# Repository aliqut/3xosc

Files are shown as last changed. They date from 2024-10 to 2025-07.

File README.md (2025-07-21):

# 3xOsc
3xOsc | 3 VCO Eurorack Module

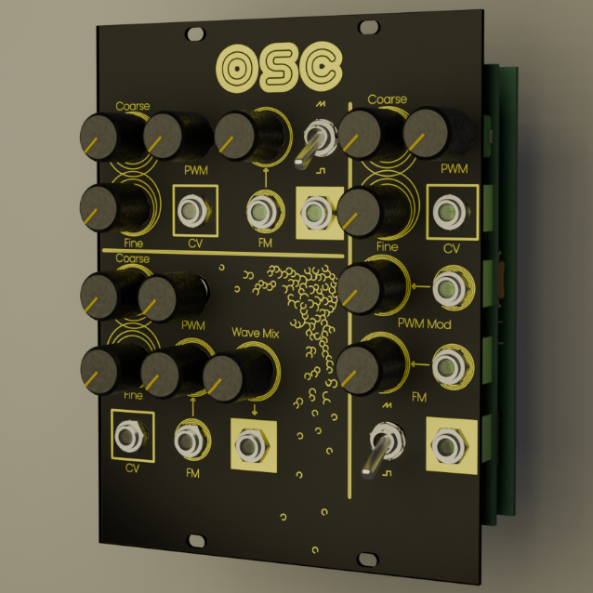
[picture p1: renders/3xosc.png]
render


This is a Eurorack format VCO synth module, based on Moritz Klein's VCO design.

The module was designed using KiCad.

---

**Features**:

Each of the 3 oscillators has:
  - Coarse and fine tuning knobs
  - a PWM (Pulse-width Modulation) knob
  - a FM (Frequency Modulation) knob and CV (Control Voltage) input

Controls unique to each oscillator:
- Oscillator 1:
  - Saw/Pulse switch
- Oscillator 2:
  - Saw/Pulse wave mix knob
- Oscillator 3:
  - Saw/Pulse switch
  - PWM modulation input, and modulation amount knob 

# Build Guide

1. Download the Gerber files from each board's '.gerbers' folder.
2. If you want to make any modifications to the schematics, download the schematics, make your modifications, and regenerate new Gerbers
3. View the components required from the `BOM.csv` file. (If you have made any changes to the schematics, it is best to regenerate the BOMs).
4. Order all the components needed
5. Send the Gerber files for PCB manufacturing, you can use [PCBShopper](https://pcbshopper.com/) to compare prices across various manufacturers.
6. Assemble the module

- **Notes**
  - Generic 1/4W 1% resistors will work for the build. 
  - The potentiometers are all linear.
    - For the coarse tuning knobs, you can use logarithmic pots if you prefer.
  - In addition to the components in the BOM, you will need M3 bolts to mount the module into your case, and hex nuts to mount the front panel onto the components (these usually come packaged with all the interface components).

Once you have your PCBs and components, refer to the BOM and schematic to solder the components onto the board.

The module is split into three boards, the main board, the connector board, and the front panel. You can make your own front panel if you'd prefer. 

The front panel board has no electrical connections and is purely aesthetic. I recommend letting your PCB manufacturer know this to avoid any issues.

The main and connector board are connected via the pin headers on the top and bottom of the PCBs, make sure you orient the pin headers properly before soldering. The front panel is secured onto the connector board using hex nuts.

### Front Panel

_To view the front panel on KiCad, you need to install the fonts in the `fonts/` folder from this repo, or replace them with your font of choice._

To get the shiny gold finish for the exposed copper used for text/graphics, make sure you get your PCB manufactured with an ENIG finish. Most PCB manufacturers offer this as an option.

I went for a black solder mask, but you get the option to choose from many different colours when ordering your PCB.

# Contributing

Pull requests are the best way to propose changes to the schematics.

1. Fork the repo and create your branch from `master`.
2. Make your changes to the design.
3. If your change directly affects the module's functionality, update the documentation.
4. Issue pull request

## Any contributions you make will be under the GPL Software License

In short, when you submit code changes, your submissions are understood to be under the same GPL license that covers the project.

## Report issues using Github's Issues tab.

I use GitHub issues to track public bugs. Report a bug by opening a new issue.

**Issue Reports** tend to have:

- A quick summary and/or background
- Steps to reproduce
  - Be specific
- What you expected would happen
- What actually happens
- Notes (possibly including why you think this might be happening, or stuff you tried that didn't work)

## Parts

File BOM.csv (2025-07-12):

MAIN BOARD
# | Reference | Qty | Value | Component/Footprint | Notes
1 | C1, C2, C7 | 3 | 2.2nF | Disc capacitor: D4.7mm_W2.5mm_P5.00mm | All components are through hole
2 | C3, C4, C5, C6, C8 | 5 | 1uF | Disc capacitor: D3.0mm_W1.6mm_P2.50mm
3 | C9, C10 | 2 | 10uF | Electrolitic capacitor :CP_Radial_D5.0mm_P2.00mm
4 | D1, D2, D3, D4, D5 | 5 | DO-15 | DO-15 P5.08mm Vertical AnodeUp
5 | J1, J3 | 2 | Conn 01x32 Socket | Connector_PinHeader_2.54mm:PinHeader 1x32 | Buy a pair of male and female headers. This is for connecting the main board to the connector board.
6 | J2 | 1 | Conn 02x05 Odd_Even | Connector_PinHeader_2.54mm:PinHeader 2x05 | Eurorack power header, keyed box 02x05 pin header
7 | Q1, Q3, Q5 | 3 | BC558 Transistor | THT TO-92_Inline
8 | Q2, Q4, Q6 | 3 | BC548 Transistor | THT TO-92_Inline
9 | R1, R4, R5, R7, R11, R13, R16, R20, R34, R37, R39, R41, R43, R46, R17, R21, R22, R25, R27, R28, R30, R32, R47 | 23 | 100K | Metalic film resistor 1/4W L9.0mm_D3.2mm_P12.70mm_Horizontal
10 | R2, R9, R35 | 3 | 1K5 | Metalic film resistor 1/4W L6.3mm_D2.5mm_P10.16mm_Horizontal
11 | R3, R10, R36 | 3 | 1K | Potentiometer Bourns 3006Y Horizontal
12 | R6, R8, R12, R14, R38, R40 | 6 | 1M | Metalic film resistor 1/4W
13 | R15, R19 | 2 | 200K | Metalic film resistor 1/4W
14 | R18, R23, R45 | 3 | 33K | Metalic film resistor 1/4W
15 | R24, R26, R29, R31, R33 | 5 | 20K | Metalic film resistor 1/4W
16 | R42, R48 | 2 | 68K | Metalic film resistor 1/4W
17 | R44 | 1 | 14K | Metalic film resistor 1/4W
18 | R49, R50 | 2 | 1K | Metalic film resistor 1/4W
19 | R51, R52 | 2 | 10R | Metalic film resistor 1/4W
20 | TH1, TH2, TH3, TH5, TH6, TH8, TH9, TH10, TH12, TH4, TH7, TH11 | 12 | 10K | Disk NTC Thermistor
21 | U1 | 1 | 40106 | 40106 Schmitt Trigger Inverter IC THT
22 | U2, U3, U4 | 3 | TL074 | TL074 Op-Amp IC THT
CONNECTOR BOARD
# | Reference | Qty | Value |  | Notes
1 | J1, J2 | 2 | Conn_01x32_Socket | 2.54mm 01x32
2 | J3, J4, J5, J6, J7, J8, J9, J10, J11, J12 | 10 | Audio Jacks | Thonk AudioJacks:Jack 3.5mm QingPu WQP-PJ366ST Vertical | Thonkiconn Jack Sockets or clones
3 | RV1, RV4, RV5, RV9, RV10, RV14 | 6 | 100K | Potentiometer Alpha RD901F-40-00D Vertical Linear | Tuning pots. You can replace the coarse tuning pots with logarithmic ones if you prefer
4 | RV2, RV3, RV6, RV7, RV11, RV12, RV13 | 7 | 1M | Potentiometer Alpha RD901F-40-00D Vertical Linear
5 | RV8 | 1 | 250K | Potentiometer Alpha RD901F-40-00D Vertical Linear | PWM Pot
6 | SW1, SW2 | 2 | SPDT Switch | SPDT-ON-ON | SPDT. These have three legs.
7 | U1, U2, U3, U4 | 4 | DIP Socket IC 7x2 | DIP Sockets for IC 7x2 | Heavily recommended. Makes it easy to swap out ICs if you're troubleshooting, and protects the ICs from heat during soldering.

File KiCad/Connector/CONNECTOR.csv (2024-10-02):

# | Reference | Qty | Value | Footprint | DNP
1 | J1, J2 | 2 | Conn_01x32_Socket | Connector_PinHeader_2.54mm:PinHeader_1x32_P2.54mm_Vertical
2 | J3, J4, J5, J6, J7, J8, J9, J10, J11, J12 | 10 | AudioJack3 | Thonk_AudioJacks:Jack_3.5mm_QingPu_WQP-PJ366ST_Vertical
3 | RV1, RV4, RV5, RV9, RV10, RV14 | 6 | 100k | Potentiometer_THT:Potentiometer_Alpha_RD901F-40-00D_Single_Vertical
4 | RV2, RV3, RV6, RV7, RV11, RV12, RV13 | 7 | 1M | Potentiometer_THT:Potentiometer_Alpha_RD901F-40-00D_Single_Vertical
5 | RV8 | 1 | 250k | Potentiometer_THT:Potentiometer_Alpha_RD901F-40-00D_Single_Vertical
6 | SW1, SW2 | 2 | SW_SPDT | Thonk_AudioJacks:DWB1-SPDT-ON-ON

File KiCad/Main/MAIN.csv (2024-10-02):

# | Reference | Qty | Value | Footprint | DNP
1 | C1, C2, C7 | 3 | 2.2nF | Capacitor_THT:C_Disc_D4.7mm_W2.5mm_P5.00mm
2 | C3, C4, C5, C6, C8 | 5 | 1uF | Capacitor_THT:C_Disc_D3.0mm_W1.6mm_P2.50mm
3 | C9, C10 | 2 | 10uF | Capacitor_THT:CP_Radial_D5.0mm_P2.00mm
4 | D1, D2, D3, D4, D5 | 5 | D | Diode_THT:D_DO-15_P5.08mm_Vertical_AnodeUp
5 | J1, J3 | 2 | Conn_01x32_Socket | Connector_PinHeader_2.54mm:PinHeader_1x32_P2.54mm_Vertical
6 | J2 | 1 | Conn_02x05_Odd_Even | Connector_PinHeader_2.54mm:PinHeader_2x05_P2.54mm_Vertical
7 | Q1, Q3, Q5 | 3 | BC558 | Package_TO_SOT_THT:TO-92_Inline
8 | Q2, Q4, Q6 | 3 | BC548 | Package_TO_SOT_THT:TO-92_Inline
9 | R1, R4, R5, R7, R11, R13, R16, R20, R34, R37, R39, R41, R43, R46 | 14 | 100K | Resistor_THT:R_Axial_DIN0309_L9.0mm_D3.2mm_P12.70mm_Horizontal
10 | R2, R9, R35 | 3 | 1K5 | Resistor_THT:R_Axial_DIN0207_L6.3mm_D2.5mm_P10.16mm_Horizontal
11 | R3, R10, R36 | 3 | 1K | Potentiometer_THT:Potentiometer_Bourns_3006Y_Horizontal
12 | R6, R8, R12, R14, R38, R40 | 6 | 1M | Resistor_THT:R_Axial_DIN0207_L6.3mm_D2.5mm_P7.62mm_Horizontal
13 | R15, R19 | 2 | 200k | Resistor_THT:R_Axial_DIN0207_L6.3mm_D2.5mm_P10.16mm_Horizontal
14 | R17, R21, R22, R25, R27, R28, R30, R32, R47 | 9 | 100k | Resistor_THT:R_Axial_DIN0309_L9.0mm_D3.2mm_P12.70mm_Horizontal
15 | R18, R23, R45 | 3 | 33k | Resistor_THT:R_Axial_DIN0207_L6.3mm_D2.5mm_P10.16mm_Horizontal
16 | R24, R26, R29, R31 | 4 | 20k | Resistor_THT:R_Axial_DIN0207_L6.3mm_D2.5mm_P7.62mm_Horizontal
17 | R33 | 1 | 20K | Resistor_THT:R_Axial_DIN0207_L6.3mm_D2.5mm_P7.62mm_Horizontal
18 | R42, R48 | 2 | 68K | Resistor_THT:R_Axial_DIN0207_L6.3mm_D2.5mm_P10.16mm_Horizontal
19 | R44 | 1 | 14K | Resistor_THT:R_Axial_DIN0207_L6.3mm_D2.5mm_P10.16mm_Horizontal
20 | R49, R50 | 2 | 1K | Resistor_THT:R_Axial_DIN0207_L6.3mm_D2.5mm_P10.16mm_Horizontal
21 | R51, R52 | 2 | 10R | Resistor_THT:R_Axial_DIN0207_L6.3mm_D2.5mm_P10.16mm_Horizontal
22 | TH1, TH2, TH3, TH5, TH6, TH8, TH9, TH10, TH12 | 9 | 10K | Resistor_THT:R_Axial_DIN0204_L3.6mm_D1.6mm_P2.54mm_Vertical
23 | TH4, TH7, TH11 | 3 | 10k | Resistor_THT:R_Axial_DIN0204_L3.6mm_D1.6mm_P2.54mm_Vertical
24 | U1 | 1 | 40106 | Package_DIP:DIP-14_W7.62mm_Socket
25 | U2, U3, U4 | 3 | TL074 | Package_DIP:DIP-14_W7.62mm_Socket

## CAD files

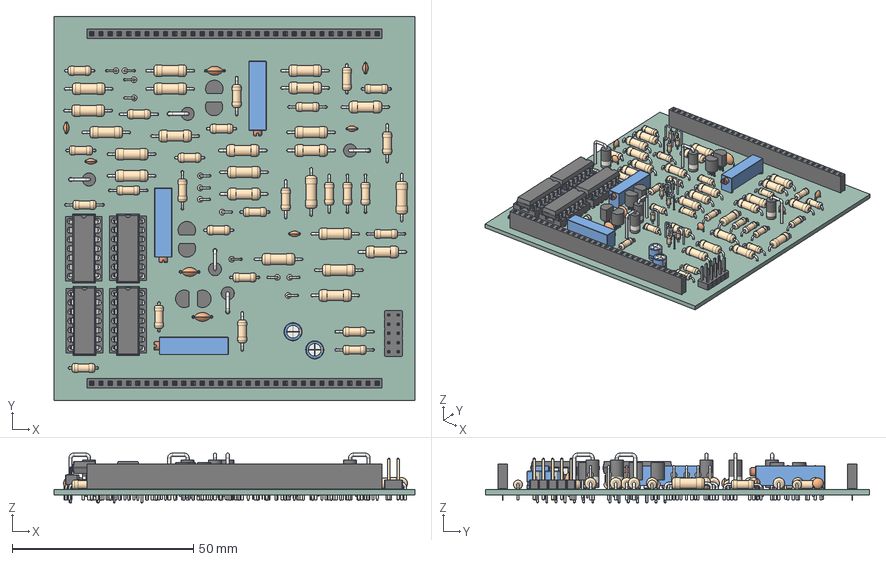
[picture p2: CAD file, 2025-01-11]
KiCad/Main/MAIN.step
99.6 x 106.0 x 13.7 mm
3X VCO PCB

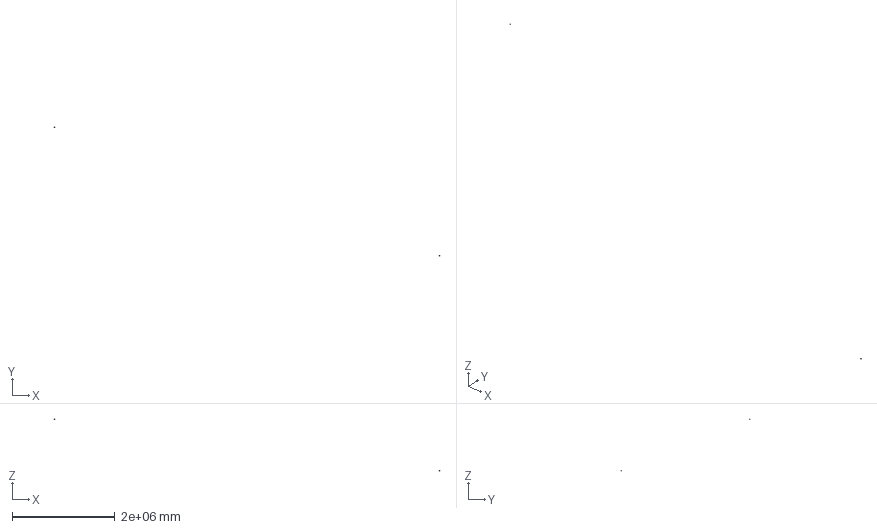
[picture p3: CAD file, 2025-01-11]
KiCad/Connector/CONNECTOR.step
7500096.3 x 2500076.7 x 1000028.5 mm
VCO PANEL PCB

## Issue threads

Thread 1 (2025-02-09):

About the Box power header orientation

IhnnChocoFarms, 2025-02-09:
Hi, while not exactly an issue there is no info on the orientation of the 2x5 box pin header. I would assume that below the square pad would be the stripe so the square pad indicates the pin 1, -12v.
Is this correct ?
Thanks

aliqut, 2025-02-09:
Your assumption is correct. The square pad (pin 1) is -12V.

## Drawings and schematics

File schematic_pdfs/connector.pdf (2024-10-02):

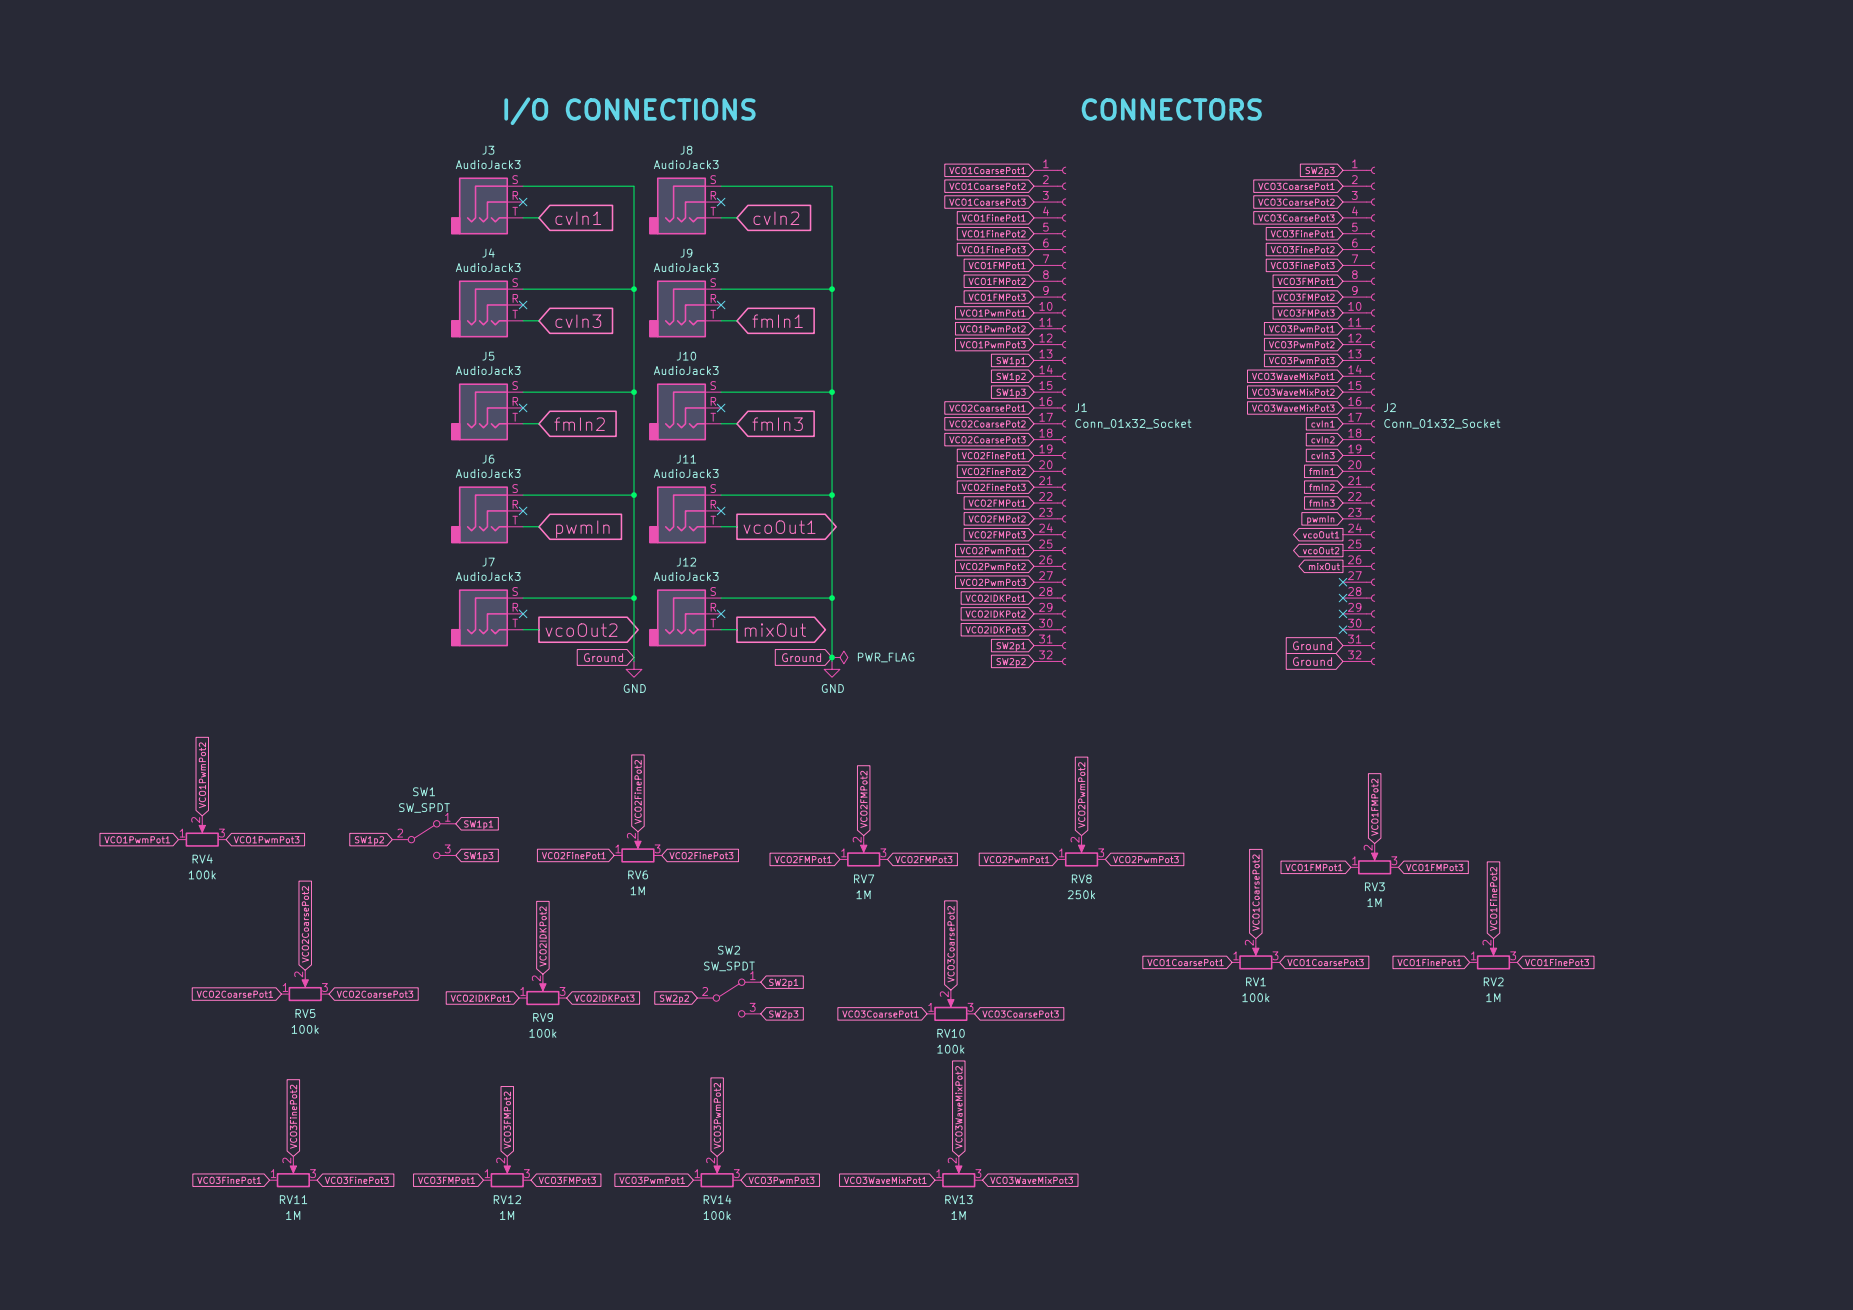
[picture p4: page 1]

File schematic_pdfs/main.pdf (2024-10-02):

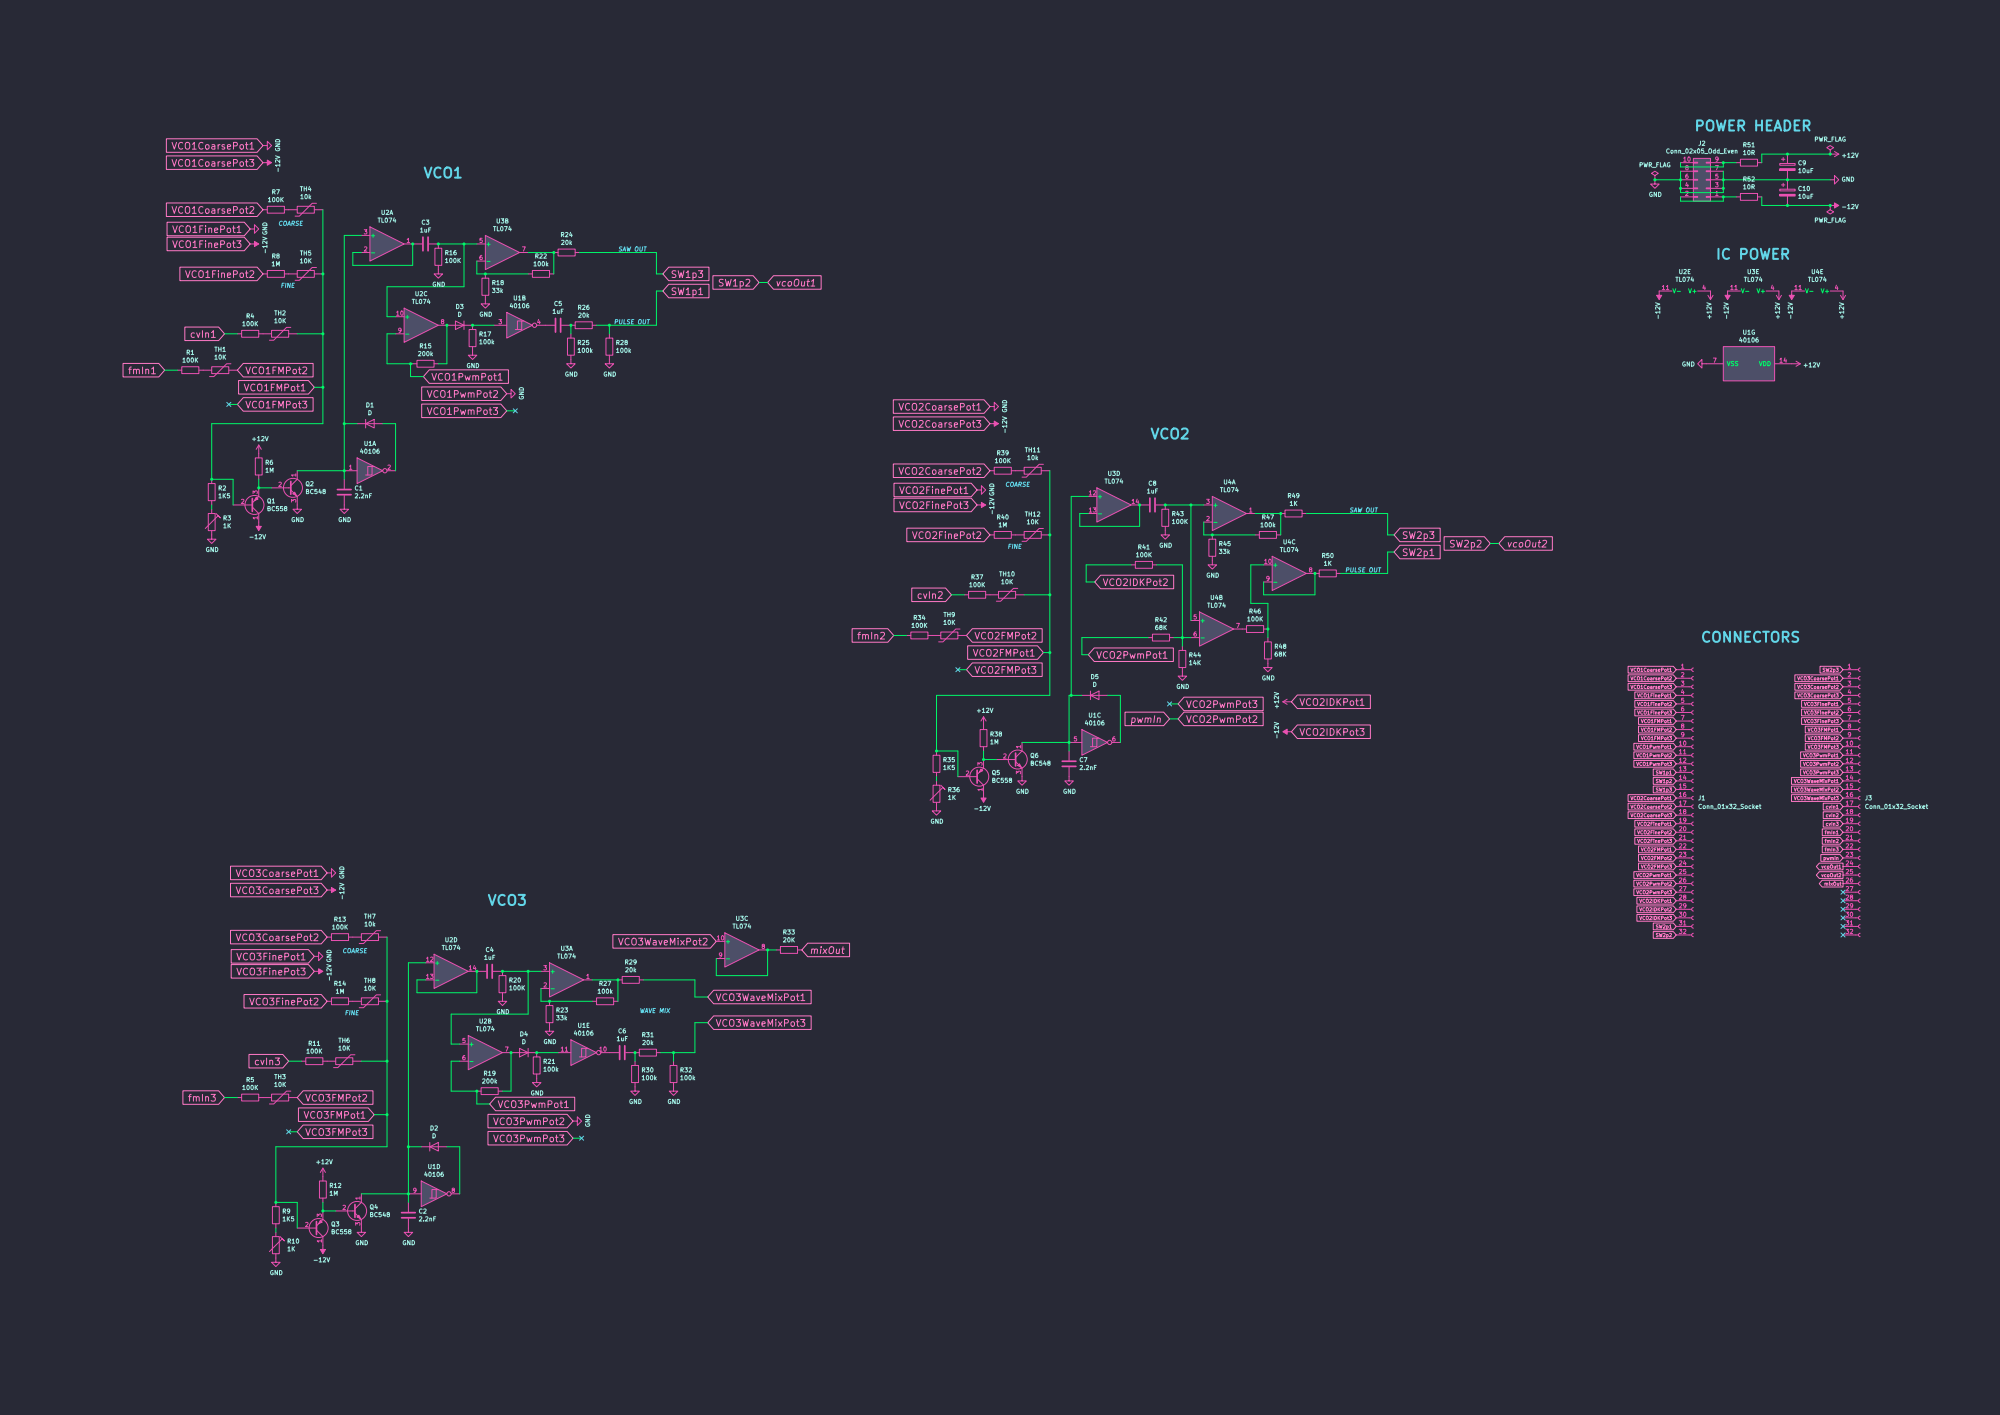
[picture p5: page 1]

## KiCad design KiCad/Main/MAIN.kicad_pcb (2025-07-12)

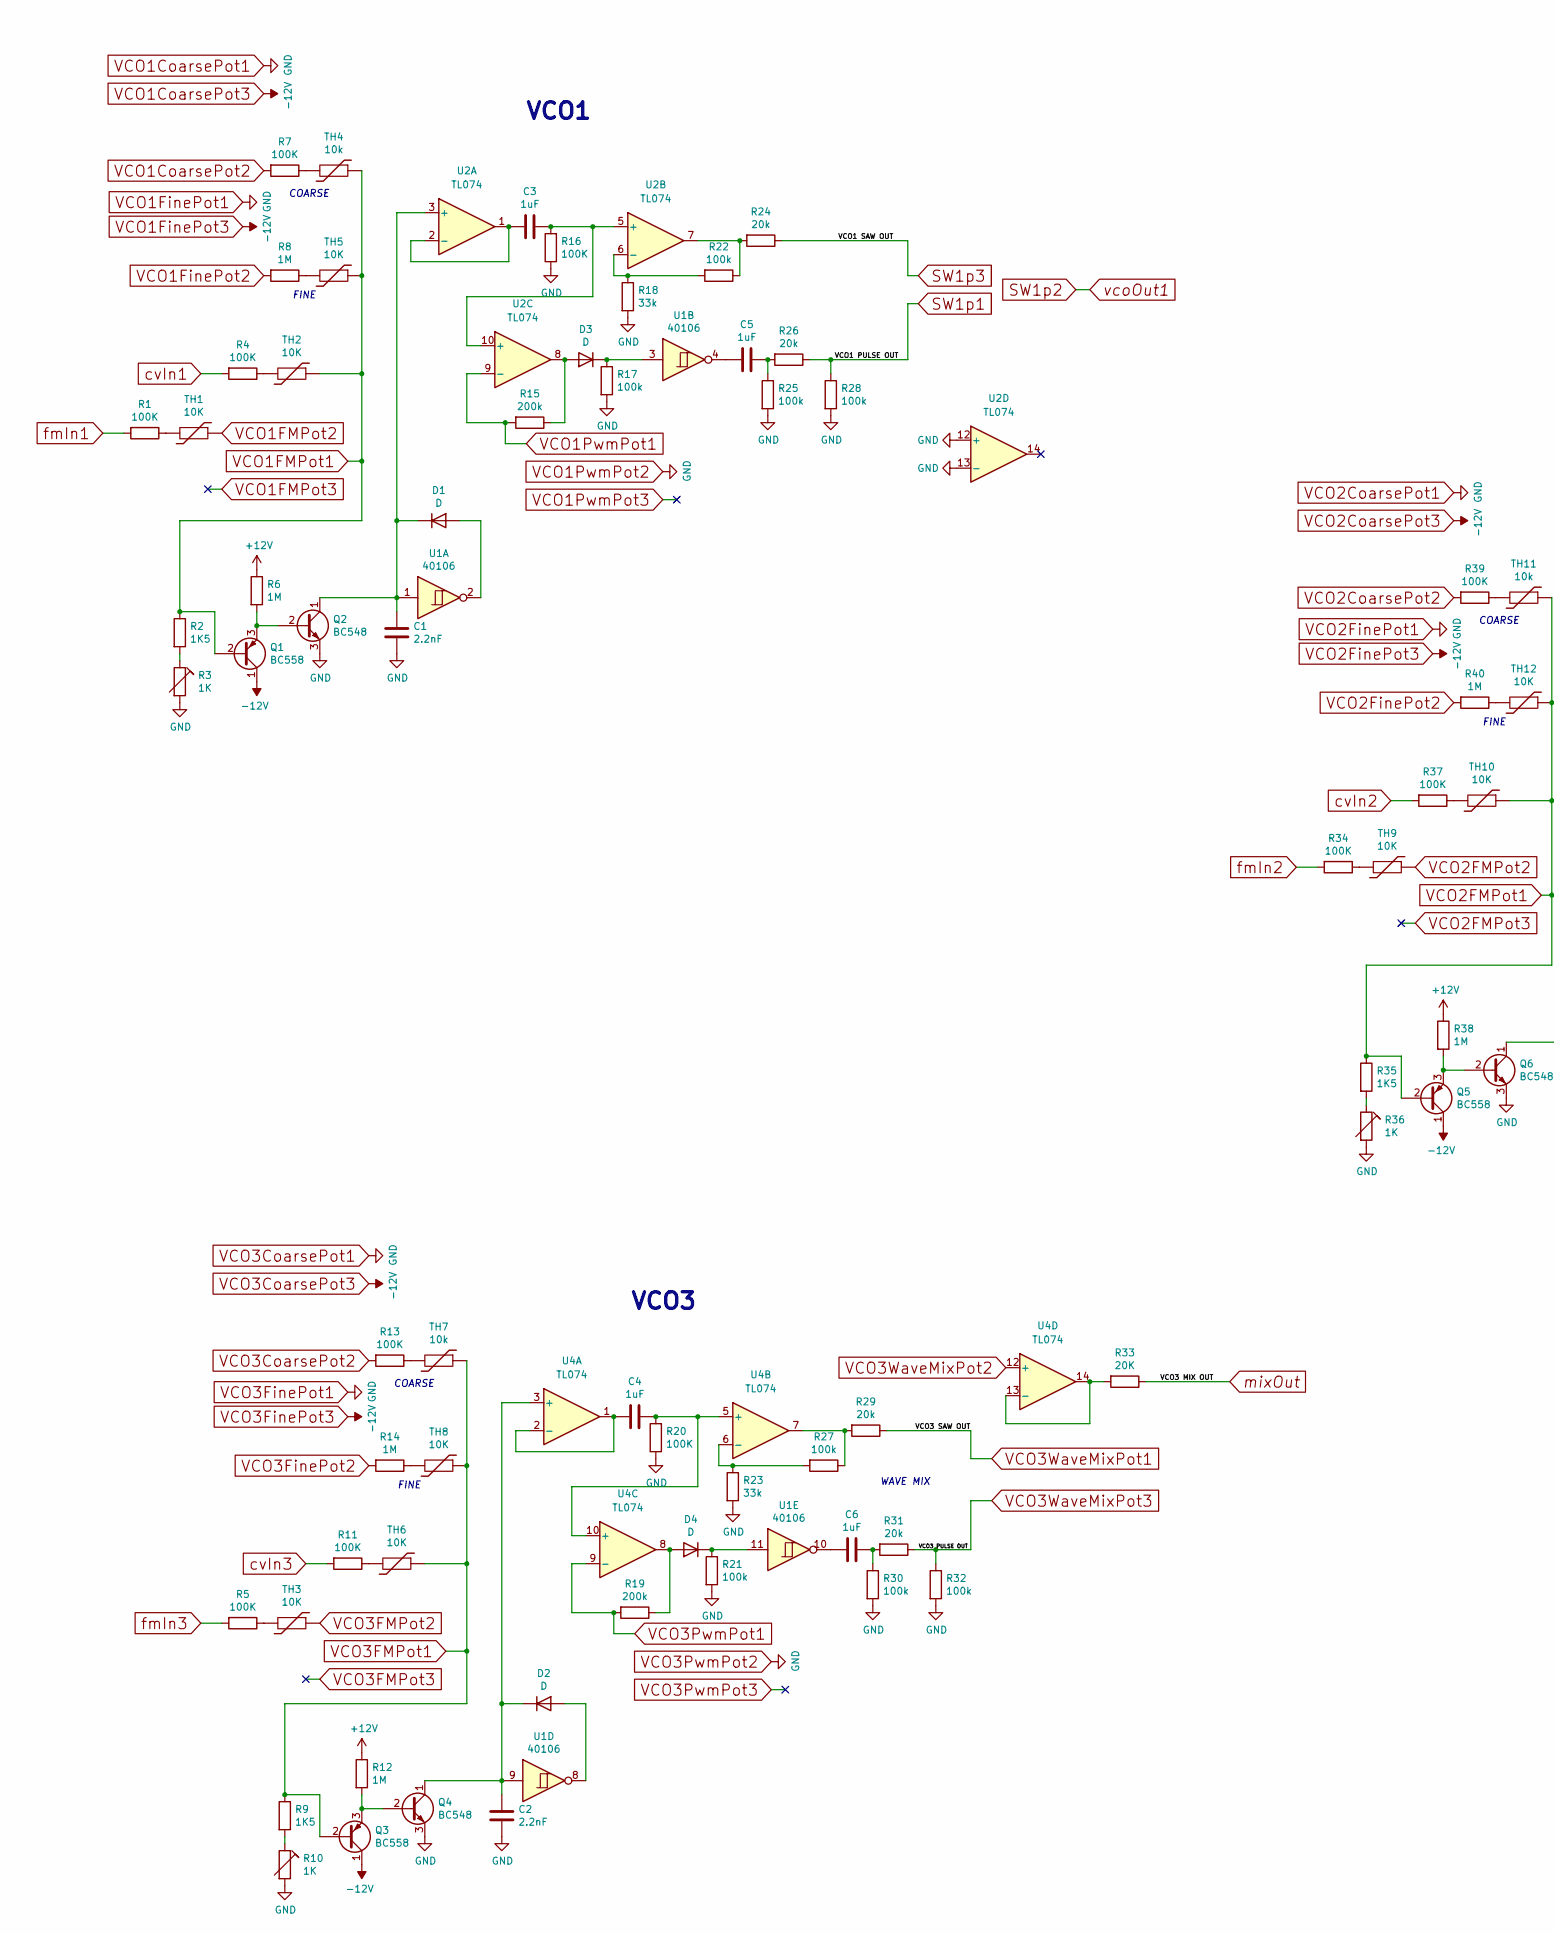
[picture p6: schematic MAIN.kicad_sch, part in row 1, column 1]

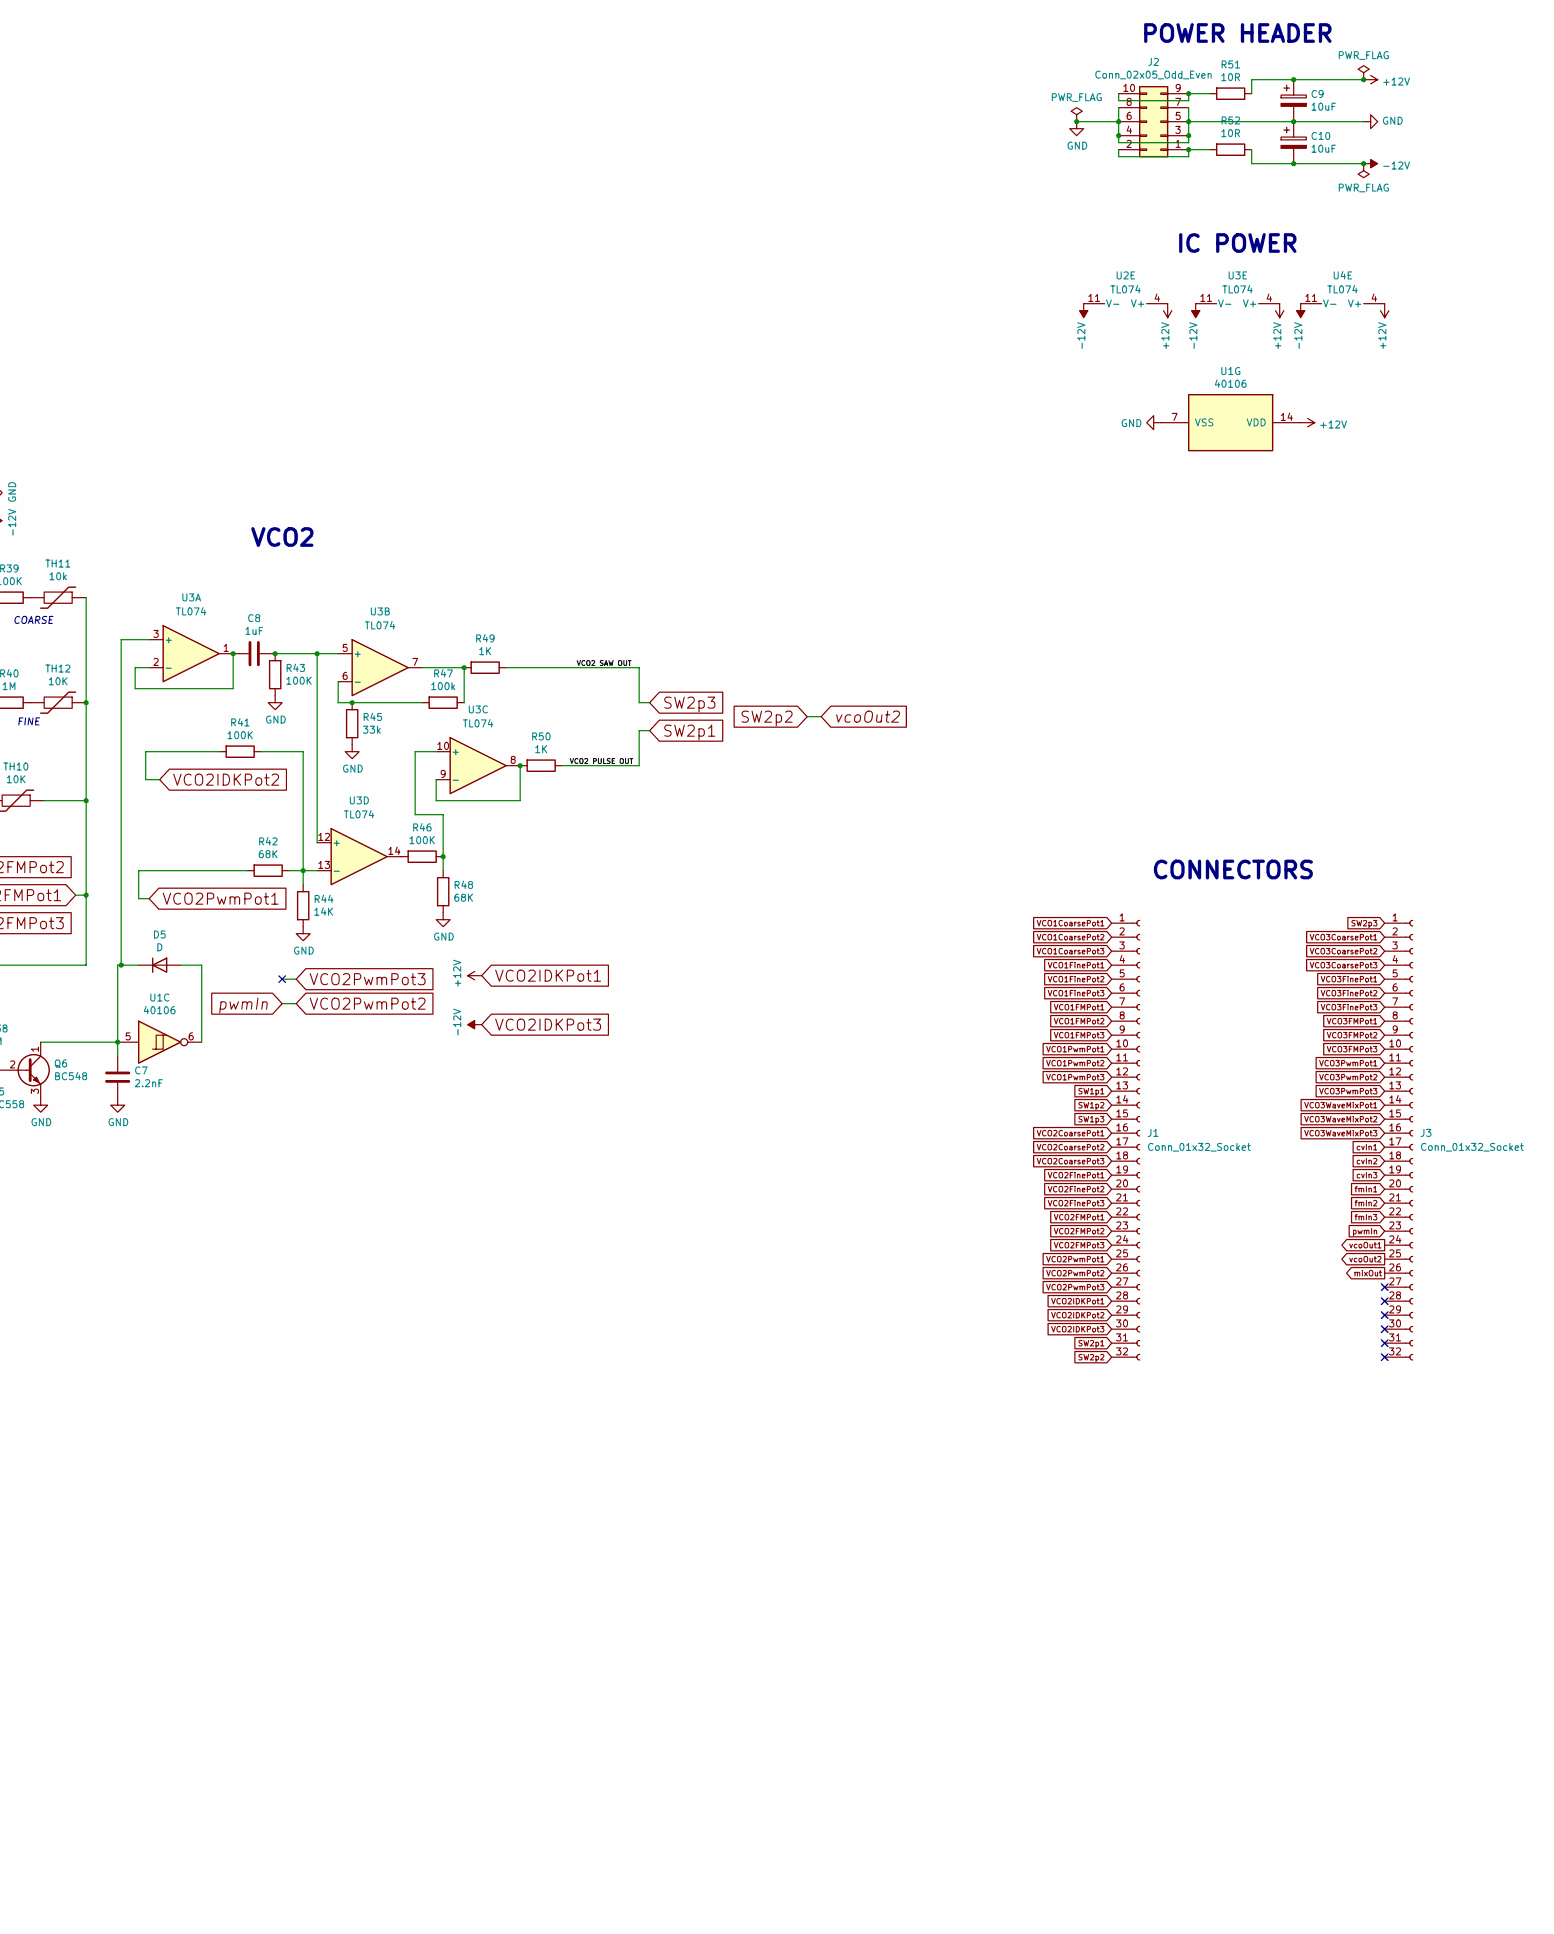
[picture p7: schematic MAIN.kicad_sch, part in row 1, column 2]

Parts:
C1, C2, C7: 2.2nF; C_Disc_D4.7mm_W2.5mm_P5.00mm
C3, C4, C5, C6, C8: 1uF; C_Disc_D3.0mm_W1.6mm_P2.50mm
C9, C10: 10uF; CP_Radial_D5.0mm_P2.00mm
D1, D2, D3, D4, D5: D; D_DO-15_P5.08mm_Vertical_AnodeUp
J1, J3: Conn_01x32_Socket; PinHeader_1x32_P2.54mm_Vertical
J2: Conn_02x05_Odd_Even; PinHeader_2x05_P2.54mm_Vertical
Q1, Q3, Q5: BC558; TO-92_Inline
Q2, Q4, Q6: BC548; TO-92_Inline
R1, R4, R5, R7, R11, R13, R16, R20, R34, R37, R39, R41, R43, R46: 100K; R_Axial_DIN0309_L9.0mm_D3.2mm_P12.70mm_Horizontal
R2, R9, R35: 1K5; R_Axial_DIN0207_L6.3mm_D2.5mm_P10.16mm_Horizontal
R3, R10, R36: 1K; Potentiometer_Bourns_3006Y_Horizontal
R6, R8, R12, R14, R38, R40: 1M; R_Axial_DIN0207_L6.3mm_D2.5mm_P7.62mm_Horizontal
R15, R19: 200k; R_Axial_DIN0207_L6.3mm_D2.5mm_P10.16mm_Horizontal
R17, R21, R22, R25, R27, R28, R30, R32, R47: 100k; R_Axial_DIN0309_L9.0mm_D3.2mm_P12.70mm_Horizontal
R18, R23, R45: 33k; R_Axial_DIN0207_L6.3mm_D2.5mm_P10.16mm_Horizontal
R24, R26, R29, R31: 20k; R_Axial_DIN0207_L6.3mm_D2.5mm_P7.62mm_Horizontal
R33: 20K; R_Axial_DIN0207_L6.3mm_D2.5mm_P7.62mm_Horizontal
R42, R48: 68K; R_Axial_DIN0207_L6.3mm_D2.5mm_P10.16mm_Horizontal
R44: 14K; R_Axial_DIN0207_L6.3mm_D2.5mm_P10.16mm_Horizontal
R49, R50: 1K; R_Axial_DIN0207_L6.3mm_D2.5mm_P10.16mm_Horizontal
R51, R52: 10R; R_Axial_DIN0207_L6.3mm_D2.5mm_P10.16mm_Horizontal
TH1, TH2, TH3, TH5, TH6, TH8, TH9, TH10, TH12: 10K; R_Axial_DIN0204_L3.6mm_D1.6mm_P2.54mm_Vertical
TH4, TH7, TH11: 10k; R_Axial_DIN0204_L3.6mm_D1.6mm_P2.54mm_Vertical
U1: 40106; DIP-14_W7.62mm_Socket
U2, U3, U4: TL074; DIP-14_W7.62mm_Socket

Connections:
unnamed: C5.1, R25.1, R26.2
unnamed: C5.2, U1.4
unnamed: C6.1, R30.1, R31.2
unnamed: C6.2, U1.10
unnamed: D1.2 (A), U1.2
unnamed: C1.1, D1.1 (K), Q2.1 (C), U1.1, U2.3 (+)
unnamed: D2.2 (A), U1.8
unnamed: C2.1, D2.1 (K), Q4.1 (C), U1.9, U4.3 (+)
unnamed: D3.2 (A), R15.1, U2.8
unnamed: D3.1 (K), R17.1, U1.3
unnamed: D4.2 (A), R19.1, U4.8
unnamed: D4.1 (K), R21.1, U1.11
unnamed: D5.2 (A), U1.6
unnamed: C7.1, D5.1 (K), Q6.1 (C), U1.5, U3.3 (+)
unnamed: J2.1, J2.2, R52.2
unnamed: J2.9, J2.10, R51.2
unnamed: Q1.3 (E), Q2.2 (B), R6.2
unnamed: Q3.3 (E), Q4.2 (B), R12.2
unnamed: Q5.3 (E), Q6.2 (B), R38.2
unnamed: R1.1, TH1.2
unnamed: R2.2, R3.1
unnamed: R4.1, TH2.2
unnamed: R5.1, TH3.2
unnamed: R7.1, TH4.2
unnamed: R8.1, TH5.2
unnamed: R9.2, R10.1
unnamed: R11.1, TH6.2
unnamed: R13.1, TH7.2
unnamed: R14.1, TH8.2
unnamed: R22.1, R24.2, U2.7
unnamed: R27.1, R29.2, U4.7
unnamed: R34.1, TH9.2
unnamed: R35.2, R36.1
unnamed: R37.1, TH10.2
unnamed: R39.1, TH11.2
unnamed: R40.1, TH12.2
unnamed: R46.2, U3.14
unnamed: R47.1, R49.2, U3.7
unnamed: C3.2, U2.1, U2.2 (-)
unnamed: C3.1, R16.2, U2.5 (+), U2.10 (+)
unnamed: R18.1, R22.2, U2.6 (-)
unnamed: C8.2, U3.1, U3.2 (-)
unnamed: C8.1, R43.2, U3.5 (+), U3.12 (+)
unnamed: R45.1, R47.2, U3.6 (-)
unnamed: R46.1, R48.1, U3.10 (+)
unnamed: R50.2, U3.8, U3.9 (-)
unnamed: R41.1, R42.1, R44.1, U3.13 (-)
unnamed: C4.2, U4.1, U4.2 (-)
unnamed: C4.1, R20.2, U4.5 (+), U4.10 (+)
unnamed: R23.1, R27.2, U4.6 (-)
unnamed: R33.2, U4.13 (-), U4.14
SW1p1: J1.13, R26.1, R28.1
SW1p2: J1.14, J3.24
SW1p3: J1.15, R24.1
SW2p1: J1.31, R50.1
SW2p2: J1.32, J3.25
SW2p3: J3.1, R49.1
VCO1CoarsePot1: C1.2, C2.2, C7.2, C9.2, C10.1, J1.1, J1.4, J1.11, J1.16, J1.19, J2.3, J2.4, J2.5, J2.6, J2.7, J2.8, J3.2, J3.5, J3.12, Q2.3 (E), Q4.3 (E), Q6.3 (E), R3.2, R10.2, R16.1, R17.2, R18.2, R20.1, R21.2, R23.2, R25.2, R28.2, R30.2, R32.2, R36.2, R43.1, R44.2, R45.2, R48.2, U1.7 (VSS), U2.12 (+), U2.13 (-)
VCO1CoarsePot2: J1.2, R7.2
VCO1CoarsePot3: C10.2, J1.3, J1.6, J1.18, J1.21, J1.30, J3.4, J3.7, Q1.1 (C), Q3.1 (C), Q5.1 (C), R52.1, U2.11 (V-), U3.11 (V-), U4.11 (V-)
VCO1FMPot1: J1.7, Q1.2 (B), R2.1, TH2.1, TH4.1, TH5.1
VCO1FMPot2: J1.8, TH1.1
VCO1FMPot3: J1.9
VCO1FinePot2: J1.5, R8.2
VCO1PwmPot1: J1.10, R15.2, U2.9 (-)
VCO1PwmPot3: J1.12
VCO2CoarsePot2: J1.17, R39.2
VCO2FMPot1: J1.22, Q5.2 (B), R35.1, TH10.1, TH11.1, TH12.1
VCO2FMPot2: J1.23, TH9.1
VCO2FMPot3: J1.24
VCO2FinePot2: J1.20, R40.2
VCO2IDKPot1: C9.1, J1.28, R6.1, R12.1, R38.1, R51.1, U1.14 (VDD), U2.4 (V+), U3.4 (V+), U4.4 (V+)
VCO2IDKPot2: J1.29, R41.2
VCO2PwmPot1: J1.25, R42.2
VCO2PwmPot2: J1.26, J3.23
VCO2PwmPot3: J1.27
VCO3CoarsePot2: J3.3, R13.2
VCO3FMPot1: J3.8, Q3.2 (B), R9.1, TH6.1, TH7.1, TH8.1
VCO3FMPot2: J3.9, TH3.1
VCO3FMPot3: J3.10
VCO3FinePot2: J3.6, R14.2
VCO3PwmPot1: J3.11, R19.2, U4.9 (-)
VCO3PwmPot3: J3.13
VCO3WaveMixPot1: J3.14, R29.1
VCO3WaveMixPot2: J3.15, U4.12 (+)
VCO3WaveMixPot3: J3.16, R31.1, R32.1
cvIn1: J3.17, R4.2
cvIn2: J3.18, R37.2
cvIn3: J3.19, R11.2
fmIn1: J3.20, R1.2
fmIn2: J3.21, R34.2
fmIn3: J3.22, R5.2
mixOut: J3.26, R33.1

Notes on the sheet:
WAVE MIX
COARSE
VCO1
FINE
VCO3
IC POWER
POWER HEADER
CONNECTORS
VCO2

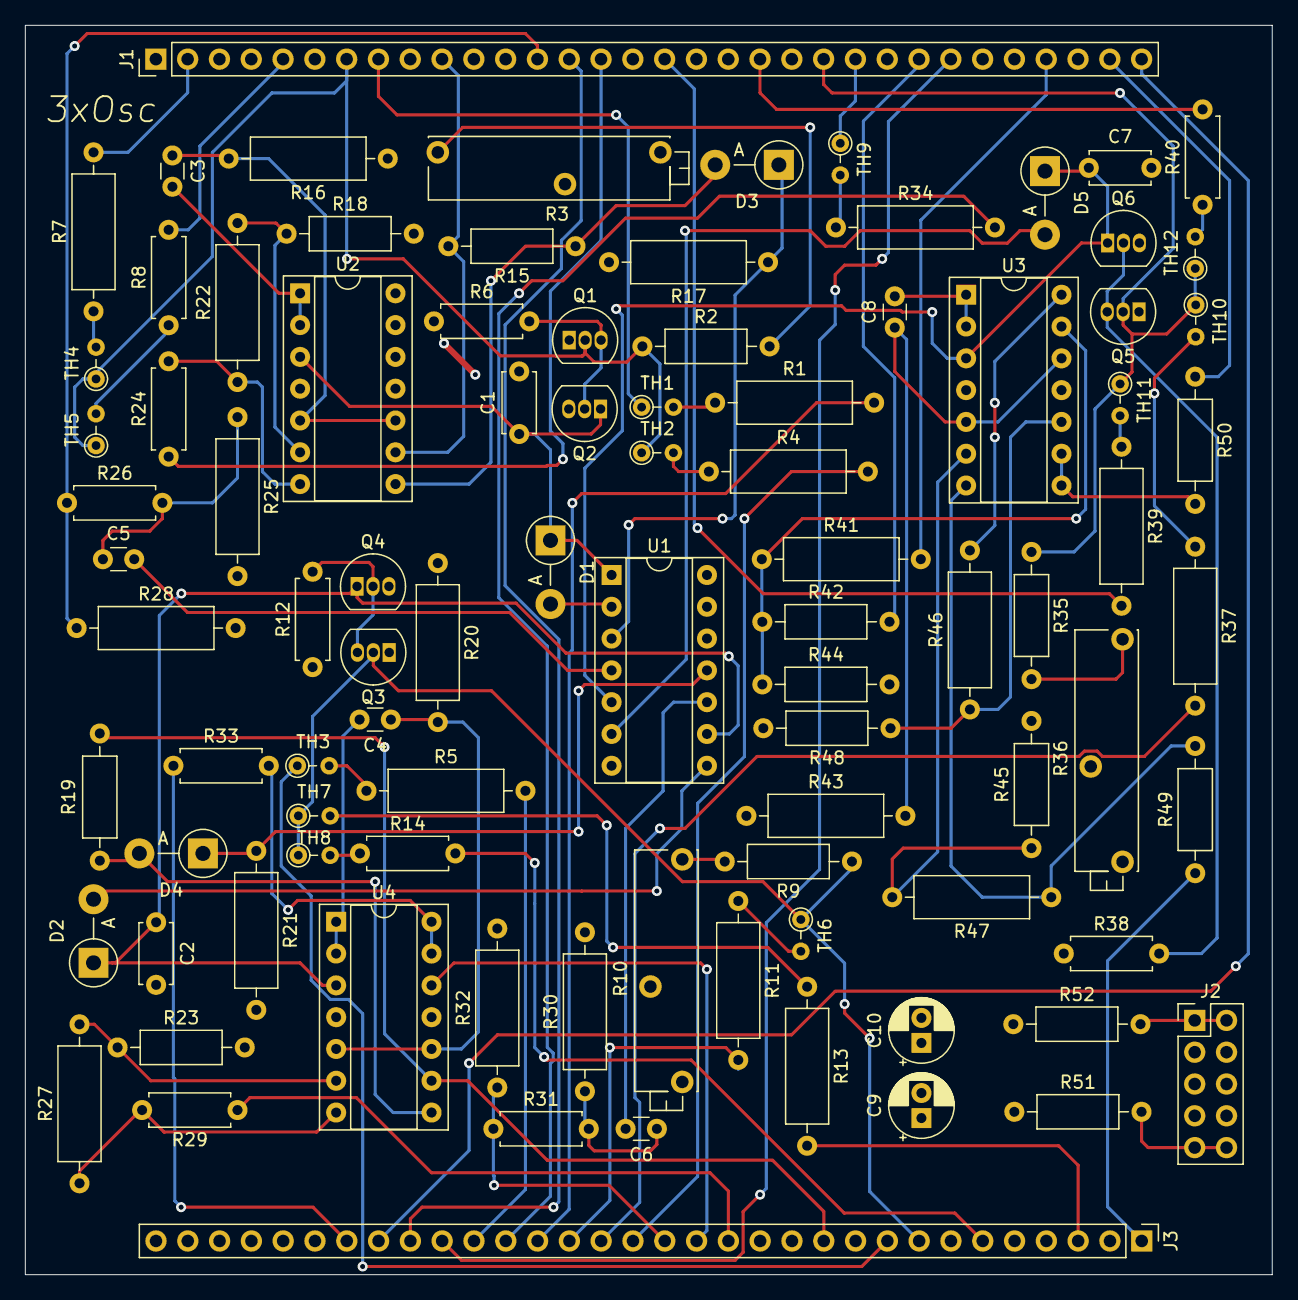
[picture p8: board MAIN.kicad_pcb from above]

Board: 4 copper layers, 99.6 x 99.8 mm, 92 parts (0 on the bottom side), 87 nets.

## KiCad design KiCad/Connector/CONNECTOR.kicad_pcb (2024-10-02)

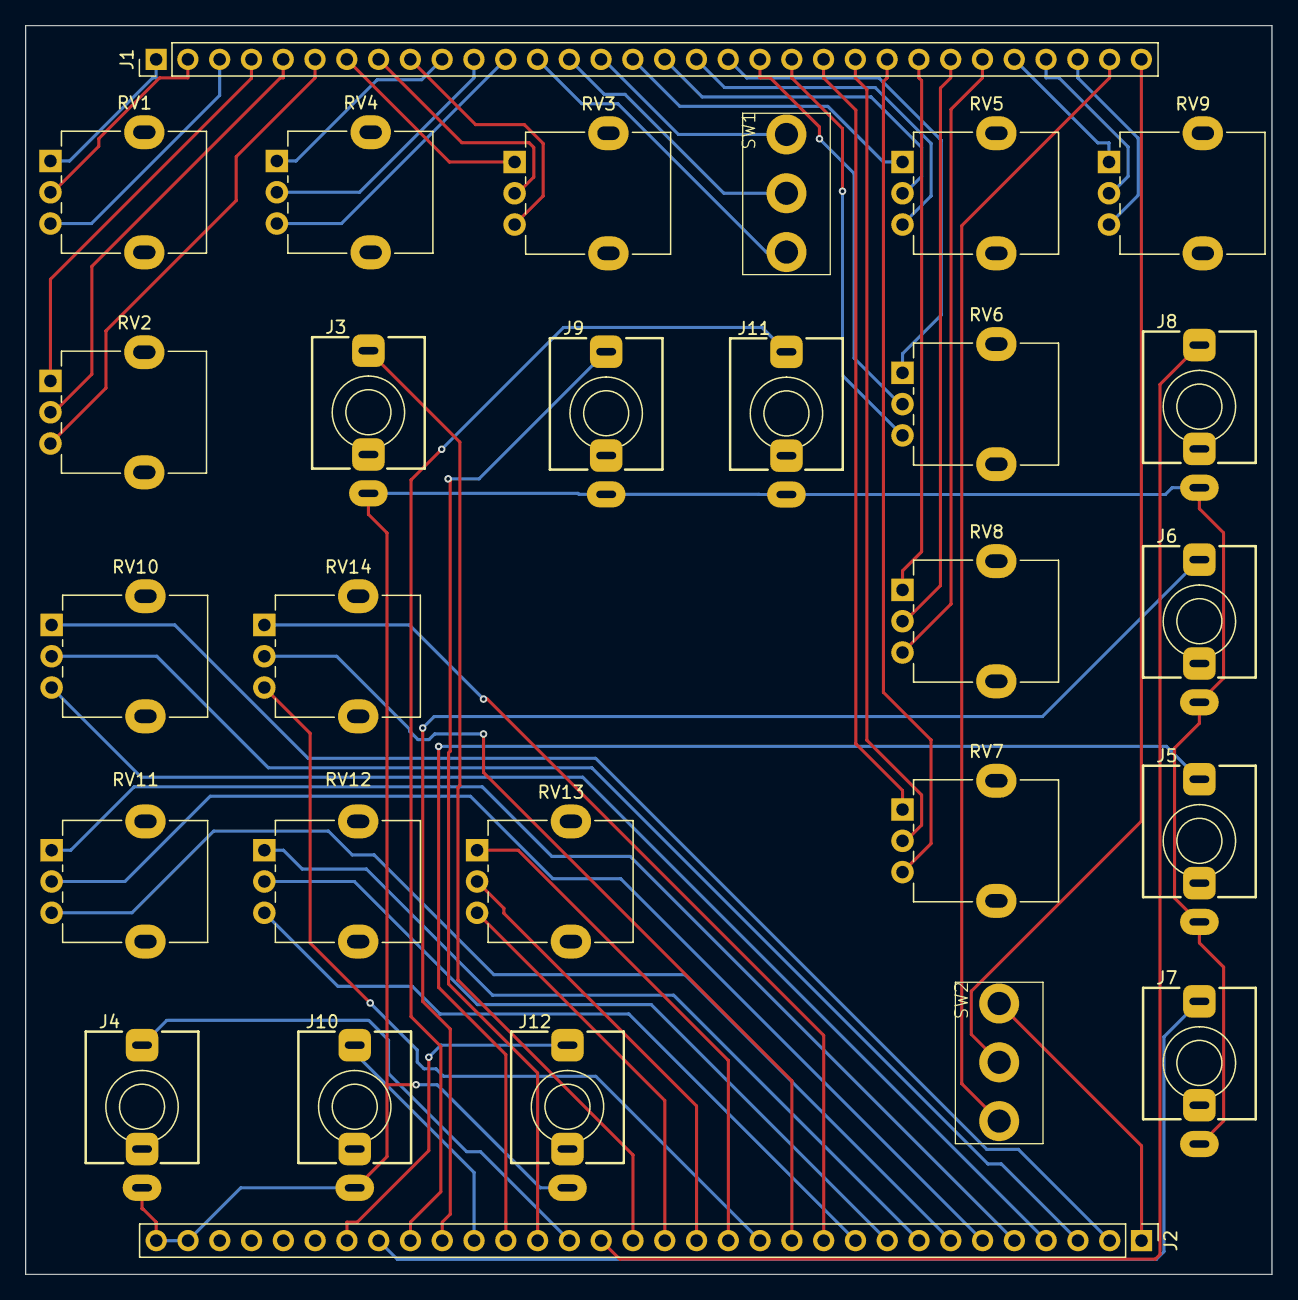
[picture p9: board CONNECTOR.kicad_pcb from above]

Board: 2 copper layers, 99.6 x 99.8 mm, 28 parts (0 on the bottom side), 59 nets.

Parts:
J1, J2: Conn_01x32_Socket; PinHeader_1x32_P2.54mm_Vertical
J3, J4, J5, J6, J7, J8, J9, J10, J11, J12: AudioJack3; Jack_3.5mm_QingPu_WQP-PJ366ST_Vertical
RV1, RV4, RV5, RV9, RV10, RV14: 100k; Potentiometer_Alpha_RD901F-40-00D_Single_Vertical
RV2, RV3, RV6, RV7, RV11, RV12, RV13: 1M; Potentiometer_Alpha_RD901F-40-00D_Single_Vertical
RV8: 250k; Potentiometer_Alpha_RD901F-40-00D_Single_Vertical
SW1, SW2: SW_SPDT; DWB1-SPDT-ON-ON

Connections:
Ground: J2.31, J2.32, J3.S, J4.S, J5.S, J6.S, J7.S, J8.S, J9.S, J10.S, J11.S, J12.S
SW1p1: J1.13, SW1.1 (A)
SW1p2: J1.14, SW1.2 (B)
SW1p3: J1.15, SW1.3 (C)
SW2p1: J1.31, SW2.1 (A)
SW2p2: J1.32, SW2.2 (B)
SW2p3: J2.1, SW2.3 (C)
VCO1CoarsePot1: J1.1, RV1.1
VCO1CoarsePot2: J1.2, RV1.2
VCO1CoarsePot3: J1.3, RV1.3
VCO1FMPot1: J1.7, RV3.1
VCO1FMPot2: J1.8, RV3.2
VCO1FMPot3: J1.9, RV3.3
VCO1FinePot1: J1.4, RV2.1
VCO1FinePot2: J1.5, RV2.2
VCO1FinePot3: J1.6, RV2.3
VCO1PwmPot1: J1.10, RV4.1
VCO1PwmPot2: J1.11, RV4.2
VCO1PwmPot3: J1.12, RV4.3
VCO2CoarsePot1: J1.16, RV5.1
VCO2CoarsePot2: J1.17, RV5.2
VCO2CoarsePot3: J1.18, RV5.3
VCO2FMPot1: J1.22, RV7.1
VCO2FMPot2: J1.23, RV7.2
VCO2FMPot3: J1.24, RV7.3
VCO2FinePot1: J1.19, RV6.1
VCO2FinePot2: J1.20, RV6.2
VCO2FinePot3: J1.21, RV6.3
VCO2IDKPot1: J1.28, RV9.1
VCO2IDKPot2: J1.29, RV9.2
VCO2IDKPot3: J1.30, RV9.3
VCO2PwmPot1: J1.25, RV8.1
VCO2PwmPot2: J1.26, RV8.2
VCO2PwmPot3: J1.27, RV8.3
VCO3CoarsePot1: J2.2, RV10.1
VCO3CoarsePot2: J2.3, RV10.2
VCO3CoarsePot3: J2.4, RV10.3
VCO3FMPot1: J2.8, RV12.1
VCO3FMPot2: J2.9, RV12.2
VCO3FMPot3: J2.10, RV12.3
VCO3FinePot1: J2.5, RV11.1
VCO3FinePot2: J2.6, RV11.2
VCO3FinePot3: J2.7, RV11.3
VCO3PwmPot1: J2.11, RV14.1
VCO3PwmPot2: J2.12, RV14.2
VCO3PwmPot3: J2.13, RV14.3
VCO3WaveMixPot1: J2.14, RV13.1
VCO3WaveMixPot2: J2.15, RV13.2
VCO3WaveMixPot3: J2.16, RV13.3
cvIn1: J2.17, J3.T
cvIn2: J2.18, J8.T
cvIn3: J2.19, J4.T
fmIn1: J2.20, J9.T
fmIn2: J2.21, J5.T
fmIn3: J2.22, J10.T
mixOut: J2.26, J12.T
pwmIn: J2.23, J6.T
vcoOut1: J2.24, J11.T
vcoOut2: J2.25, J7.T

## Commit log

2024-10-02 docs: add schematic PDFs
2024-10-03 refactor: Change main schematic to Op-Amp per VCO. Add net labels for VCO outputs
    [3X VCO.kicad_sch]
2025-01-11 refactor: Rename KiCad files
    [3X VCO.kicad_pcb, CONNECTOR.csv, CONNECTOR.kicad_pcb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]
2025-01-11 feat: Add BOM CSV
    [BOM.csv]
2025-01-11 fix: Regenerate gerbers
    [3X VCO-B_Cu.gbr, 3X VCO-B_Mask.gbr, 3X VCO-B_Paste.gbr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]
2025-01-16 fix: Missing PCB traces in main board project & gerbers
    [MAIN-B_Cu.gbr, MAIN-B_Mask.gbr, MAIN-B_Paste.gbr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]
2025-02-19 docs: Upload gerber zip files
2025-03-13 refactor: Rework Main board PCB
    [MAIN-B_Cu.gbl, MAIN-B_Mask.gbs, MAIN-B_Paste.gbp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]
2025-03-13 docs: Update gerber zips
2025-07-12 Update BOM
    [BOM.csv, CONNECTOR.kicad_sch, MAIN.kicad_pcb]
